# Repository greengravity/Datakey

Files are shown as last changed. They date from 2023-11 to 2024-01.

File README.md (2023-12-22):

### Datastorage
## What is it?
In short, it is a physical offline-device to store secret information like account data or banking informations.  
While mobile apps can do things like this, its always possible to have some spyware installed with the last gaming app or whatever.  
Because of that i dont trust mobiles too much and so i decided to make this little project.  

# How it Works?
It is pretty simple, the device have 6 Buttons for input and a 1.7" Display for output.  
Just enter your pincode and you will be able to browse through your entries.  

Every entry have a name and up to 5 additional tokens to store informations like username/password or other things.  
You can add/delete or modify entries directly on the device, without the need of a mobile-device or computer.  

The tokens itself are entered with a virtual keyboard on the device.  
Its like entering the name with a gamecontroller on a gamingconsole.  

Everything entered will be encrypted with a masterkey and stored on a micro-sd card.  
The masterkey is a secret that only the user know, if it get lost, you may not be able to restore your data anymore.  

Usually the masterkey is stored in the device, so you dont need to rember it all the time.  
But if you or someone else mess up the pincode verification, the masterkey get deleted from the device (for security reasons).  
Thats why it is important to have the masterkey stored or memorized safely.  

The Device can also act as an keyboard.  
After you connected the device to your pc via usb, you can select an entry/token and push it to the pc.  
like entering the data with a keyboard.  
This type of communication is pretty much one-way, so the connected system cannot control the output of the device.  
It should be safe to use it like that.  

# Features
- 128-Bit AES-CBC encryption over all entries
* Offline input/output
* USB-Keyboard function to push data to connected systems
* USB-Charging
* Long standby because of low power consumption ( about 2 years - 8.5müAmp usage with 150mAh Battery )
* Usage of Fat32 filesystem, so you can backup your data on your PC, this is safe because the data is completely encrypted, but make sure the masterkey stay separated from the data (dont store the masterkey on the pc too)
+ TETRIS :)

# What do you need to start?
- The Device
* An micro sd-card, formated with a Fat32 filesystem.
+ A micro-usb cable to charge the device

Enter the sd-card to the slot on the side of the device and open it.  
You will be questioned about the masterkey.  
Enter one, the longer the better.  
Then you will be questioned about your pincode.  
This looks like a game, but it is actually just a disguise as an additional security layer.  
Enter one and Reenter it, you can use all 6 buttons for it.  
You should end up on an empty screen showing the entrylist.  
Gratulations, you can now add/modify entries in your list, using the context menus.  

# Build the Device
To build the device you need a bunch of things

The electrical components (see components.csv in the Docs)  
The Printboard (see datakeyboard/ for the kicad project or datakeyboard/gerber for the gerberfiles to send to your pcb-maker)  
The MPLAB X IDE from microchip as well as an programmer device like the PICKit to build and programm the pic24fj128gb204 microcontroller  
A 3D Printer to print the housing.  
A tiny piece of thin copper or iron and something to cut it, it become the inlay for the housing to trigger the pogopins when open or close the cap.  
A possibility to solder SMD-Parts

Checkout c0pperdragon and his amazing HotPlate project on github for this (also available on tindie)

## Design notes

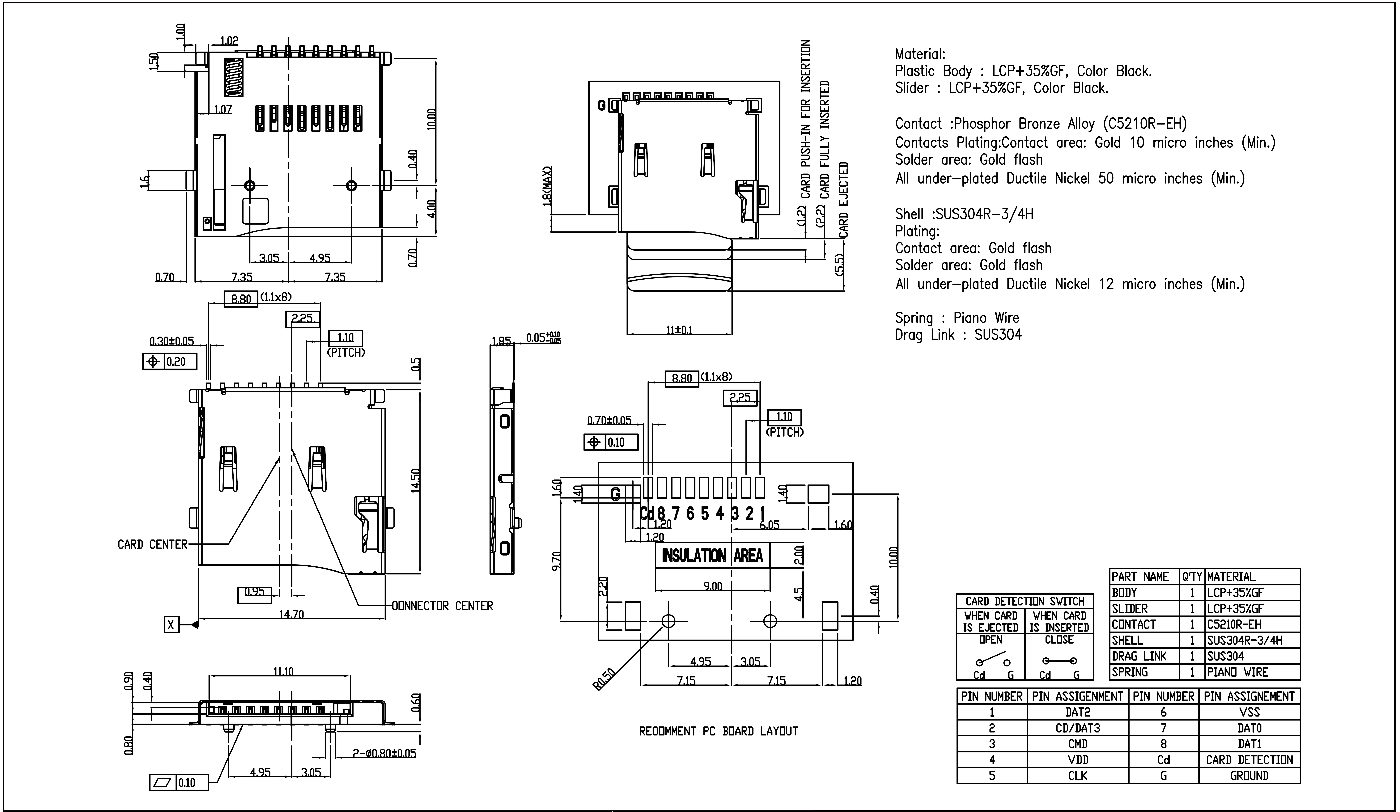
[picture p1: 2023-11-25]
docs/MICRO-SDCARD-1.jpg

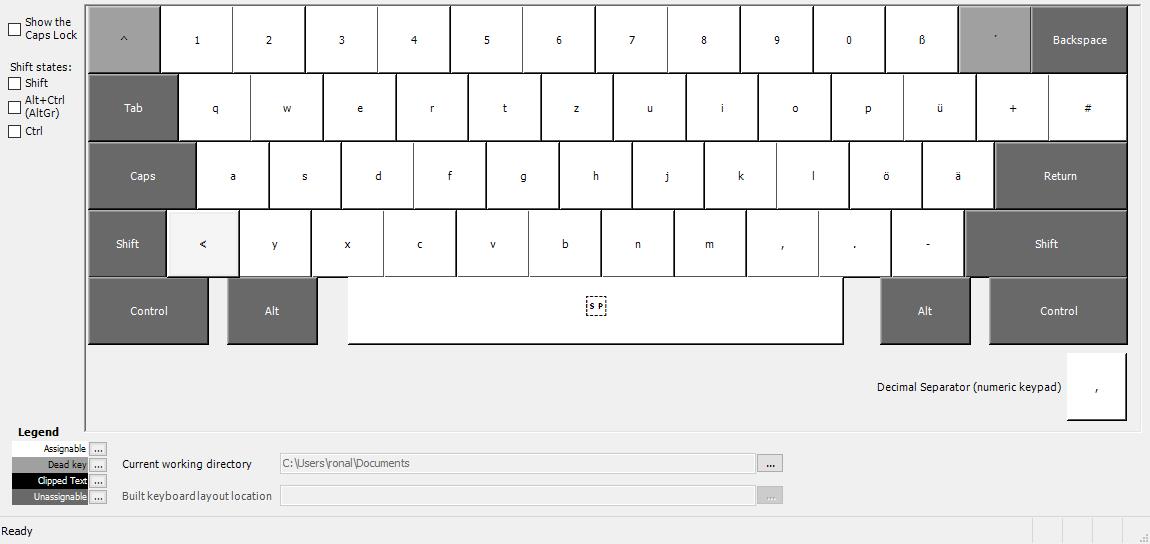
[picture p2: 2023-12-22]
assettools/locals/fonts/de-DE/Layout01.jpg

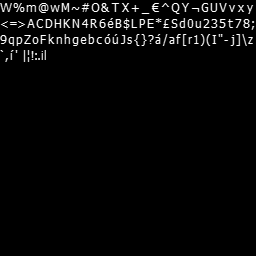
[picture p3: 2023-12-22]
assettools/locals/fonts/en-GB/font_0.png

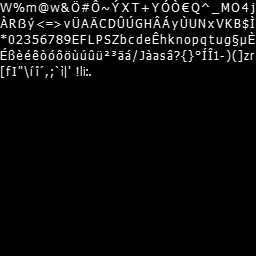
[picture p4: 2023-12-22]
assettools/locals/fonts/de-DE/font_0.png

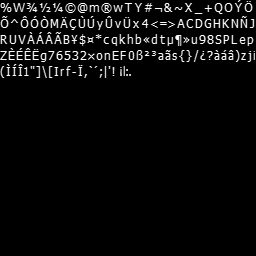
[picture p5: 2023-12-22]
assettools/locals/fonts/en-US/font_0.png

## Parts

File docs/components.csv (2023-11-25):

Item | Qty | Reference(s) | Value | LibPart | Footprint | Datasheet
1 | 3 | C1, C2, C3 | 10uF | Device:C_Small | Capacitor_SMD:C_0805_2012Metric_Pad1.18x1.45mm_HandSolder | ~
2 | 7 | C5, C6, C7, C8, C9, C10, C11 | 100nF | Device:C_Small | Capacitor_SMD:C_0603_1608Metric_Pad1.08x0.95mm_HandSolder | ~
3 | 2 | D1, D2 | LED | Device:LED | Diode_SMD:D_1206_3216Metric_Pad1.42x1.75mm_HandSolder | ~
4 | 1 | D3 | BAS40-06 | Library:BAS40-06 | Package_TO_SOT_SMD:SOT-23 | ~
6 | 1 | JCARD1 | Micro_SD_Card_Det | Connector:Micro_SD_Card_Det | Library:microSD_Unknown | Micro SD-Card slot, have a look at the image in the doc folder for the correct dimensions that match the footprint
7 | 1 | JDISP1 | Conn_01x08 | Connector_Generic:Conn_01x08 | Connector_PinHeader_2.54mm:PinHeader_1x08_P2.54mm_Vertical | Display from A-Z Delivery – have a look at the datasheet in the doc folder
9 | 1 | JUSB1 | USB_OTG | Connector:USB_OTG | Library:USB_Micro-B_Unknown | ~
10 | 5 | Q1, Q2, Q3, Q4, Q5 | NX2301P | Transistor_FET:BSS83P | Package_TO_SOT_SMD:SOT-23 | ~
11 | 1 | R1 | 100 | Device:R_Small | Resistor_SMD:R_0805_2012Metric_Pad1.20x1.40mm_HandSolder | ~
12 | 3 | R2, R3, R4 | 1k | Device:R_Small | Resistor_SMD:R_0805_2012Metric_Pad1.20x1.40mm_HandSolder | ~
13 | 1 | R5 | 2.2k | Device:R_Small | Resistor_SMD:R_0805_2012Metric_Pad1.20x1.40mm_HandSolder | ~
14 | 7 | R6, R7, R9, R10, R11, R12, R13 | 10k | Device:R_Small | Resistor_SMD:R_0805_2012Metric_Pad1.20x1.40mm_HandSolder | ~
15 | 1 | R8 | 100k | Device:R_Small | Resistor_SMD:R_0805_2012Metric_Pad1.20x1.40mm_HandSolder | ~
16 | 6 | SW1, SW2, SW3, SW4, SW5, SW6 | SW_Push | Switch:SW_Push | Button_Switch_SMD:SW_Push_1P1T_NO_6x6mm_H9.5mm | ~
17 | 1 | U1 | PIC24FJ128GB204 | Library:PIC24FJ128GB204 | Package_QFP:TQFP-44_10x10mm_P0.8mm
18 | 1 | U2 | MCP73831-2-OT | Battery_Management:MCP73831-2-OT | Package_TO_SOT_SMD:SOT-23-5 | ~
19 | 1 | U3 | STLQ015M30R | Regulator_Linear:AP131-30 | Package_TO_SOT_SMD:SOT-23-5 | ~
20 | 2 |  | 33mm extended | Pogopins |  | ~ soldered with fine cables to JCASE1 and JCASE2
21 | 1 |  | 3,7V, 150mAh | Lipo-Battery |  | https://www.amazon.de/dp/B08215WQMQ?ref=ppx_yo2ov_dt_b_product_details&th=1

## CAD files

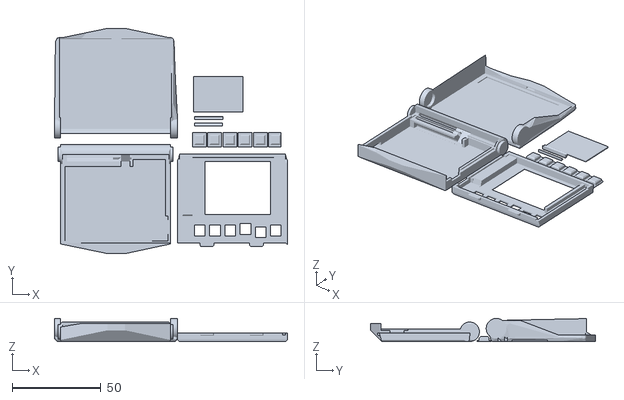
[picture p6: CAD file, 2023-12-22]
housing/housing_complete.stl
131.4 x 127.0 x 13.1

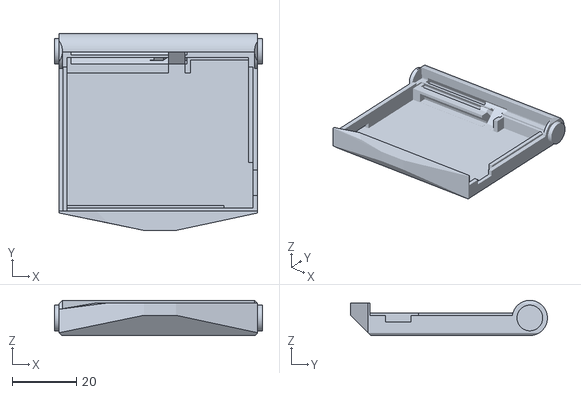
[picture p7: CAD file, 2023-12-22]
housing/gehauese.stl
65.0 x 61.5 x 11.0

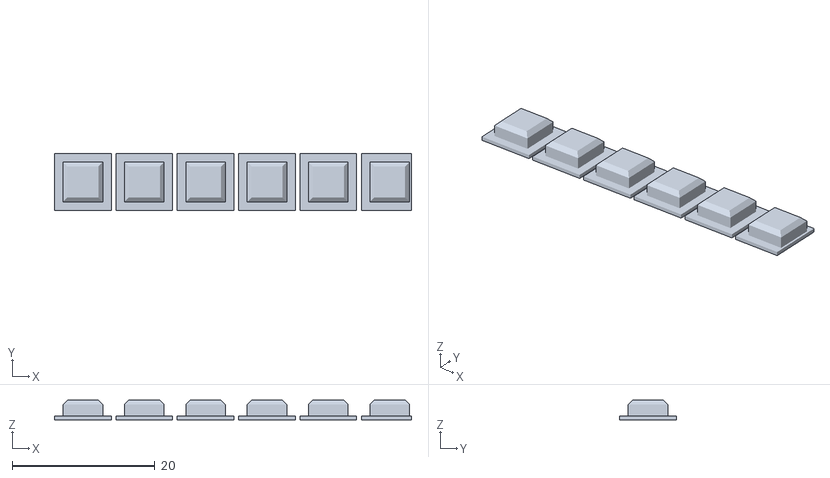
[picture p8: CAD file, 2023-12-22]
housing/buttons.stl
50.0 x 7.97 x 2.76

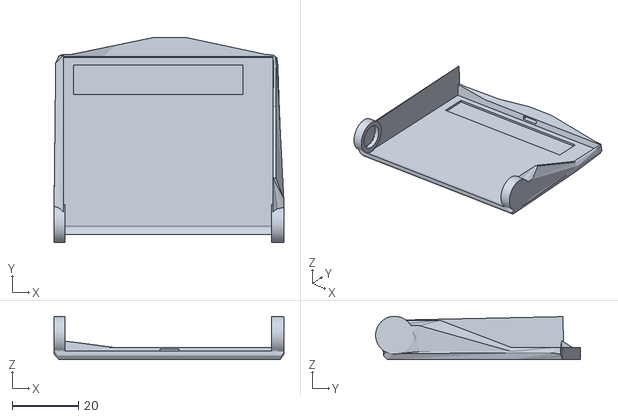
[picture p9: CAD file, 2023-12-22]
housing/deckel.stl
69.3 x 61.7 x 13.1

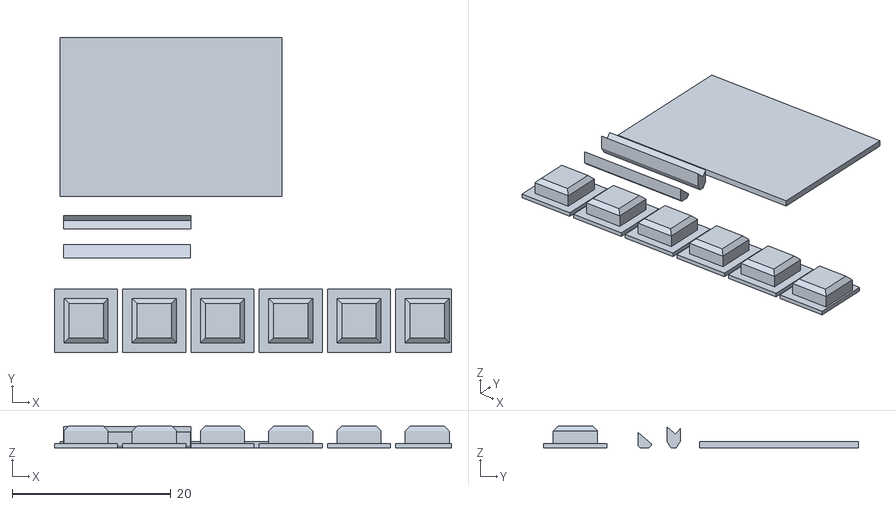
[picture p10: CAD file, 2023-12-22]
housing/extras.stl
50.0 x 39.6 x 2.76

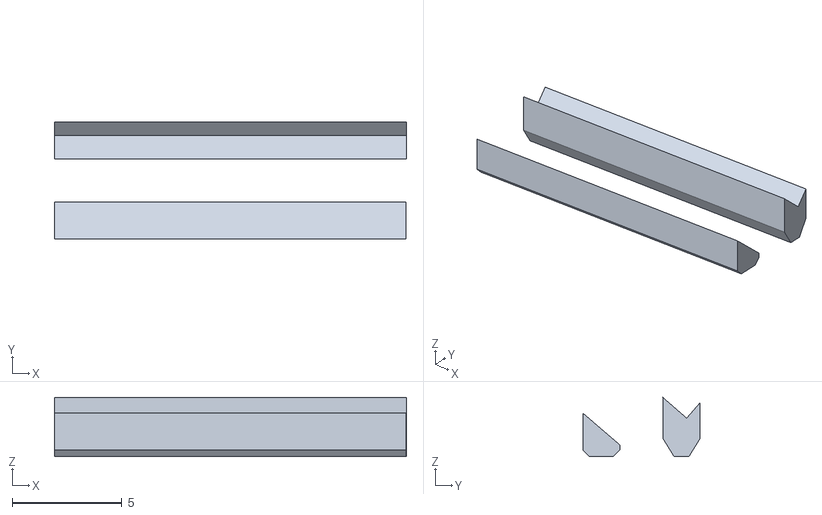
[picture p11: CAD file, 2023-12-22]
housing/pogoblock.stl
16.0 x 5.33 x 2.69

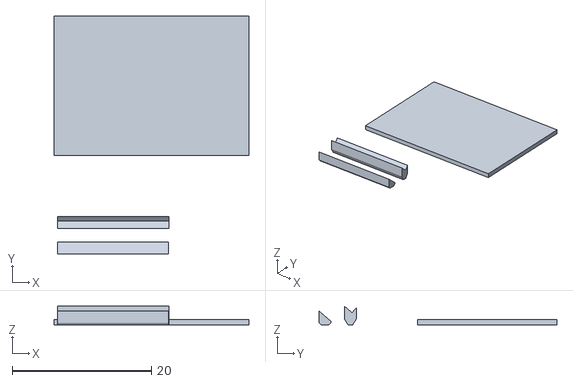
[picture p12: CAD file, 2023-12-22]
housing/einlagen.stl
28.0 x 34.1 x 2.69

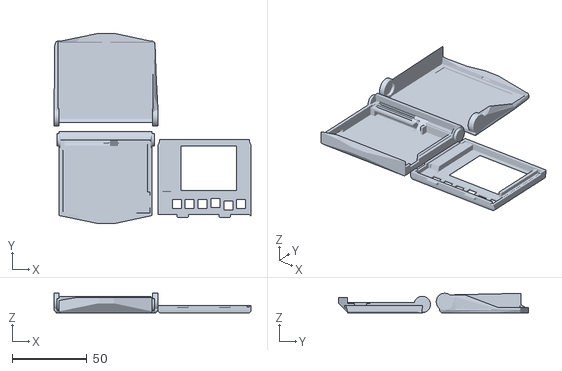
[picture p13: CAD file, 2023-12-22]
housing/housing.stl
131.4 x 127.0 x 13.1

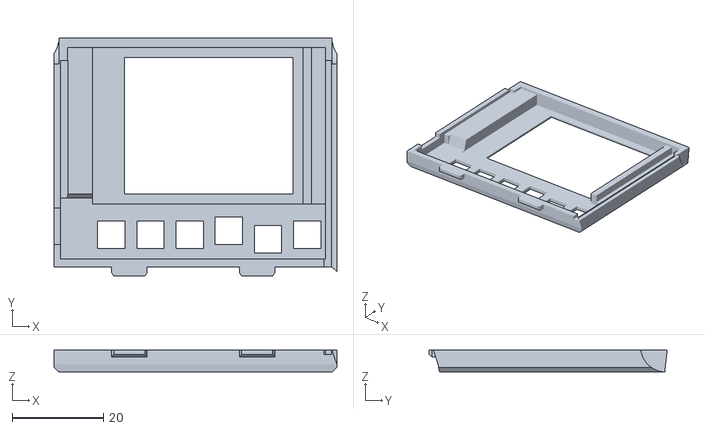
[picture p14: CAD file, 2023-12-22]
housing/gehauese_inlay.stl
62.0 x 52.2 x 4.77

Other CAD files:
housing/housing_complete.blend

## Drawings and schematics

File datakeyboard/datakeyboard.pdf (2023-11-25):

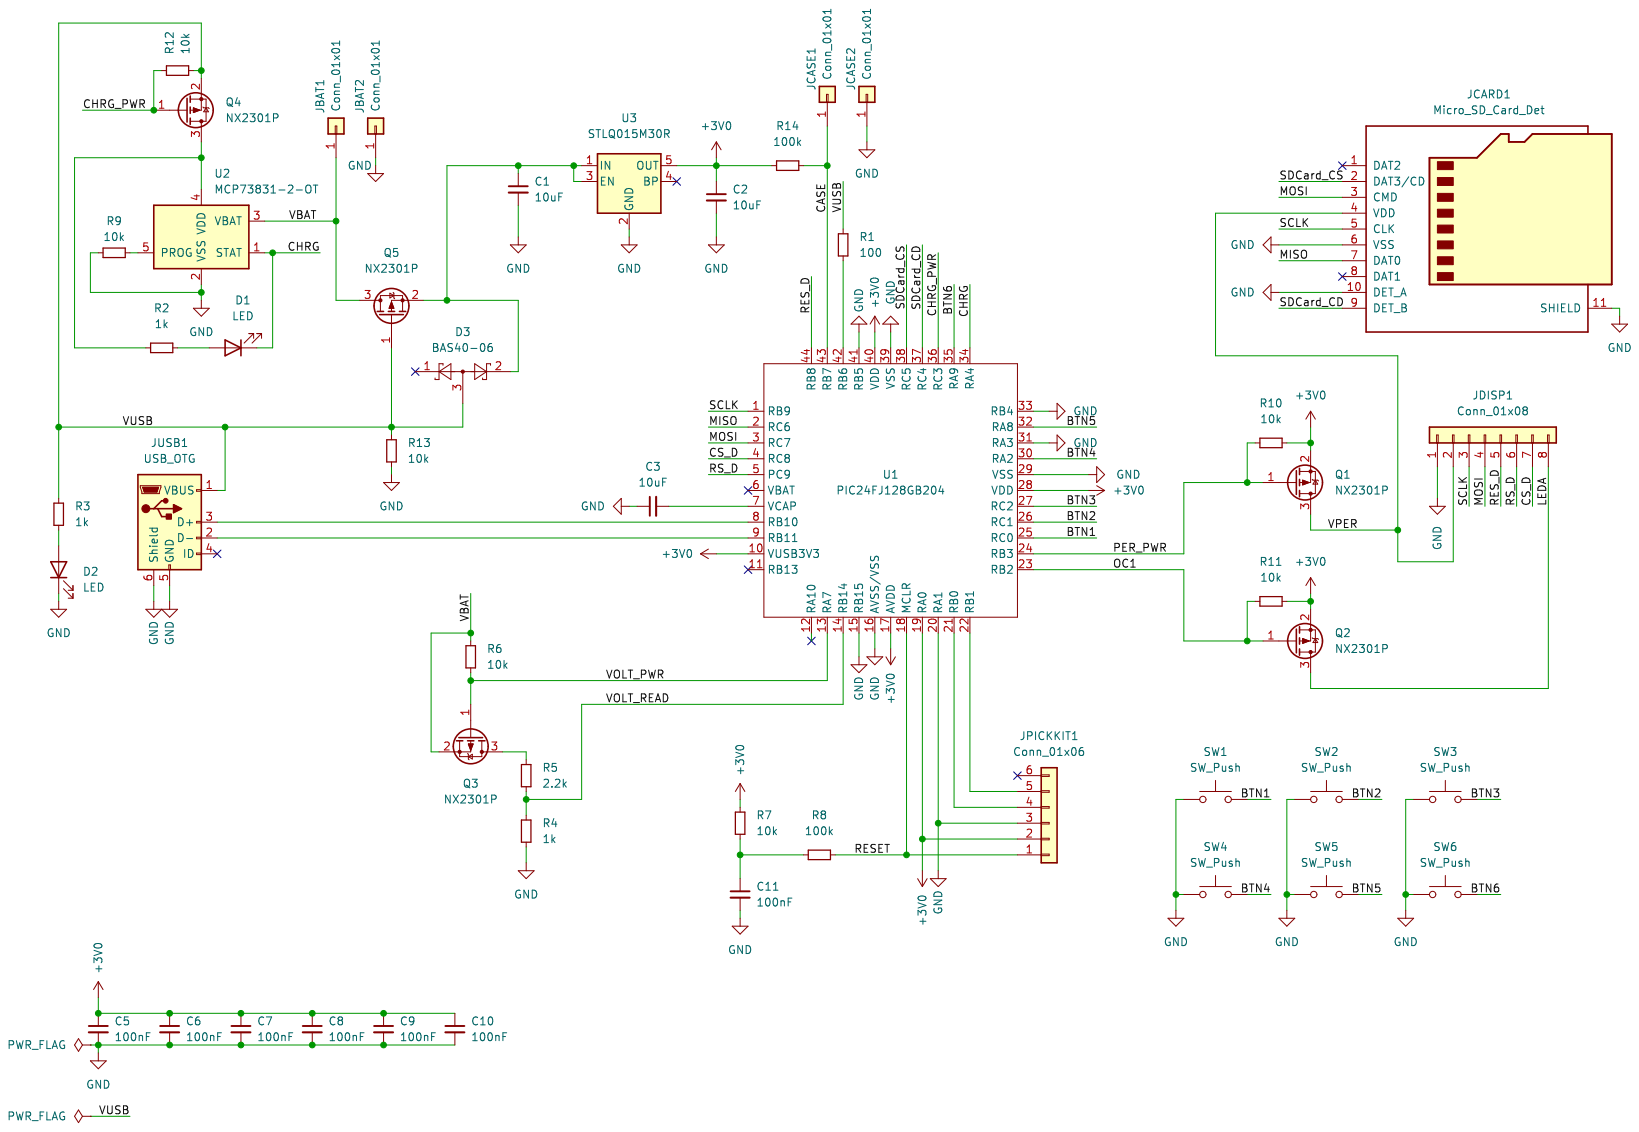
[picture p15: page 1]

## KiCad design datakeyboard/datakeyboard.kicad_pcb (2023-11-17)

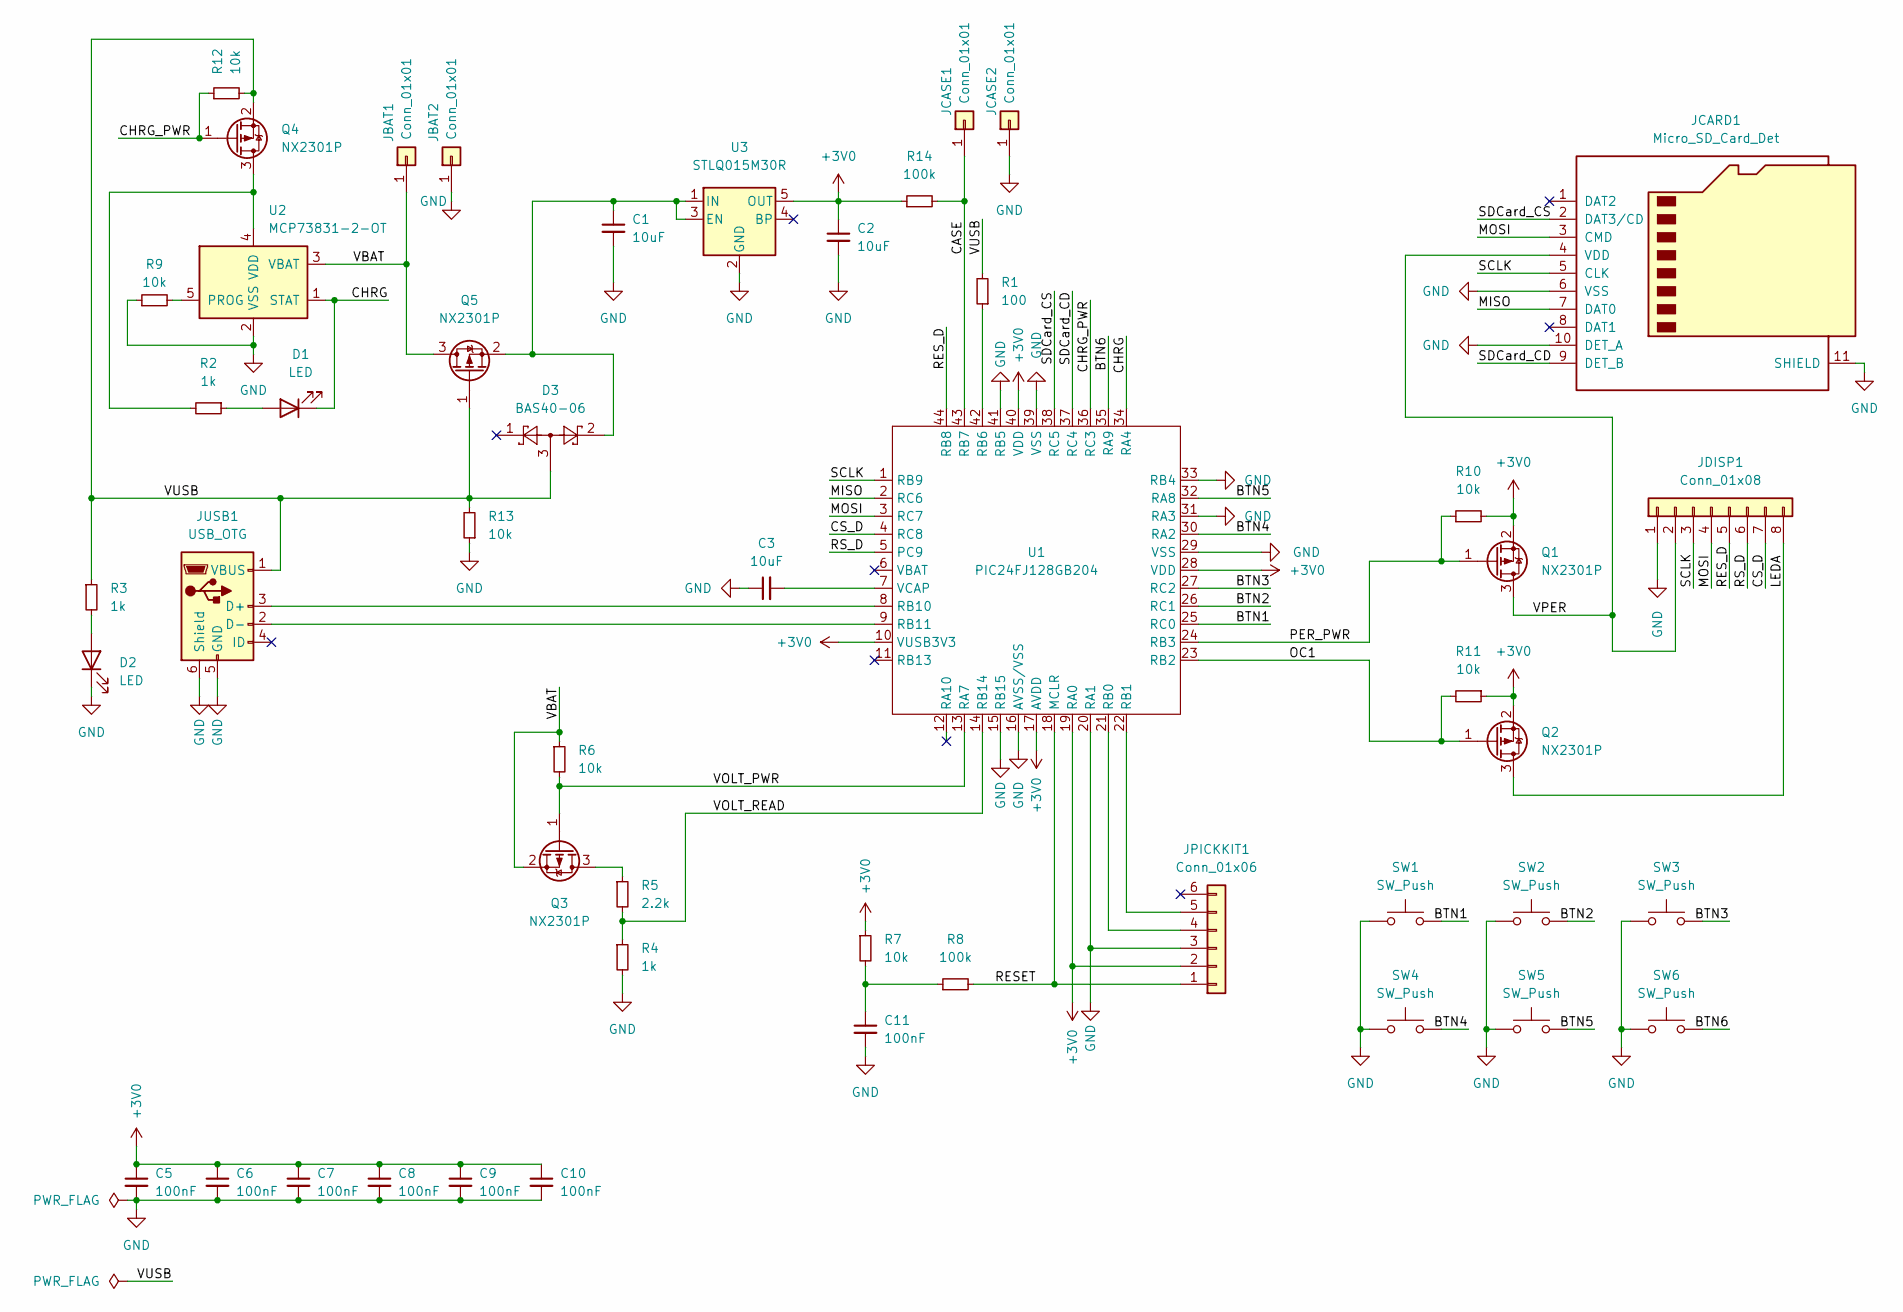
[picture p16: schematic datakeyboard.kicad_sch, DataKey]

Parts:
C1, C2, C3: 10uF; C_0805_2012Metric_Pad1.18x1.45mm_HandSolder
C5, C6, C7, C8, C9, C10, C11: 100nF; C_0603_1608Metric_Pad1.08x0.95mm_HandSolder
D1, D2: LED; D_1206_3216Metric_Pad1.42x1.75mm_HandSolder
D3: BAS40-06; SOT-23
JBAT1, JBAT2: Conn_01x01; TestPoint_Pad_2.0x2.0mm
JCARD1: Micro_SD_Card_Det; microSD_Unknown
JCASE1, JCASE2: Conn_01x01; TestPoint_Pad_2.0x2.0mm
JDISP1: Conn_01x08; PinHeader_1x08_P2.54mm_Vertical
JPICKKIT1: Conn_01x06; PinHeader_1x06_P2.54mm_Vertical
JUSB1: USB_OTG; USB_Micro-B_Unknown
Q1, Q2, Q3, Q4, Q5: NX2301P; SOT-23
R1: 100; R_0805_2012Metric_Pad1.20x1.40mm_HandSolder
R2, R3, R4: 1k; R_0805_2012Metric_Pad1.20x1.40mm_HandSolder
R5: 2.2k; R_0805_2012Metric_Pad1.20x1.40mm_HandSolder
R6, R7, R9, R10, R11, R12, R13: 10k; R_0805_2012Metric_Pad1.20x1.40mm_HandSolder
R8, R14: 100k; R_0805_2012Metric_Pad1.20x1.40mm_HandSolder
SW1, SW2, SW3, SW4, SW5, SW6: SW_Push; SW_Push_1P1T_NO_6x6mm_H9.5mm
U1: PIC24FJ128GB204; TQFP-44_10x10mm_P0.8mm
U2: MCP73831-2-OT; SOT-23-5
U3: STLQ015M30R; SOT-23-5

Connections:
+3V0: C2.1, C5.1, C6.1, C7.1, C8.1, C9.1, C10.1, JPICKKIT1.2, Q1.2 (S), Q2.2 (S), R7.1, R10.2, R11.1, R14.1, U1.10 (VUSB3V3), U1.17 (AVDD), U1.19 (RA0), U1.28 (VDD), U1.40 (VDD), U3.5 (OUT)
/BTN1: SW1.2, U1.25 (RC0)
/BTN2: SW2.2, U1.26 (RC1)
/BTN3: SW3.2, U1.27 (RC2)
/BTN4: SW4.2, U1.30 (RA2)
/BTN5: SW5.2, U1.32 (RA8)
/BTN6: SW6.2, U1.35 (RA9)
/CASE: JCASE1.1, R14.2, U1.43 (RB7)
/CHRG: D1.1 (K), U1.34 (RA4), U2.1 (STAT)
/CHRG_PWR: Q4.1 (G), R12.1, U1.36 (RC3)
/CS_D: JDISP1.7, U1.4 (RC8)
/LEDA: JDISP1.8, Q2.3 (D)
/MISO: JCARD1.7 (DAT0), U1.2 (RC6)
/MOSI: JCARD1.3 (CMD), JDISP1.4, U1.3 (RC7)
/OC1: Q2.1 (G), R11.2, U1.23 (RB2)
/PER_PWR: Q1.1 (G), R10.1, U1.24 (RB3)
/RESET: JPICKKIT1.1, R8.2, U1.18 (MCLR)
/RES_D: JDISP1.5, U1.44 (RB8)
/RS_D: JDISP1.6, U1.5 (PC9)
/SCLK: JCARD1.5 (CLK), JDISP1.3, U1.1 (RB9)
/SDCard_CD: JCARD1.9 (DET_B), U1.37 (RC4)
/SDCard_CS: JCARD1.2 (DAT3/CD), U1.38 (RC5)
/VBAT: JBAT1.1, Q3.2 (S), Q5.3 (D), R6.1, U2.3 (VBAT)
/VOLT_PWR: Q3.1 (G), R6.2, U1.13 (RA7)
/VOLT_READ: R4.1, R5.2, U1.14 (RB14)
/VPER: JCARD1.4 (VDD), JDISP1.2, Q1.3 (D)
/VUSB: D3.3, JUSB1.1 (VBUS), Q4.2 (S), Q5.1 (G), R1.2, R3.1, R12.2, R13.2
GND: C1.2, C2.2, C3.1, C5.2, C6.2, C7.2, C8.2, C9.2, C10.2, C11.2, D2.1 (K), JBAT2.1, JCARD1.6 (VSS), JCARD1.10 (DET_A), JCARD1.11 (SHIELD), JCASE2.1, JDISP1.1, JPICKKIT1.3, JUSB1.5 (GND), JUSB1.6 (Shield), R4.2, R9.1, R13.1, SW1.1, SW2.1, SW3.1, SW4.1, SW5.1, SW6.1, U1.15 (RB15), U1.16 (AVSS/VSS), U1.20 (RA1), U1.29 (VSS), U1.31 (RA3), U1.33 (RB4), U1.39 (VSS), U1.41 (RB5), U2.2 (VSS), U3.2 (GND)
unnamed: C1.1, D3.2, Q5.2 (S), U3.1 (IN), U3.3 (EN)
unnamed: C3.2, U1.7 (VCAP)
unnamed: C11.1, R7.2, R8.1
unnamed: D1.2 (A), R2.1
unnamed: D2.2 (A), R3.2
unnamed: JPICKKIT1.4, U1.21 (RB0)
unnamed: JPICKKIT1.5, U1.22 (RB1)
unnamed: JUSB1.2 (D-), U1.9 (RB11)
unnamed: JUSB1.3 (D+), U1.8 (RB10)
unnamed: Q3.3 (D), R5.1
unnamed: Q4.3 (D), R2.2, U2.4 (VDD)
unnamed: R1.1, U1.42 (RB6)
unnamed: R9.2, U2.5 (PROG)

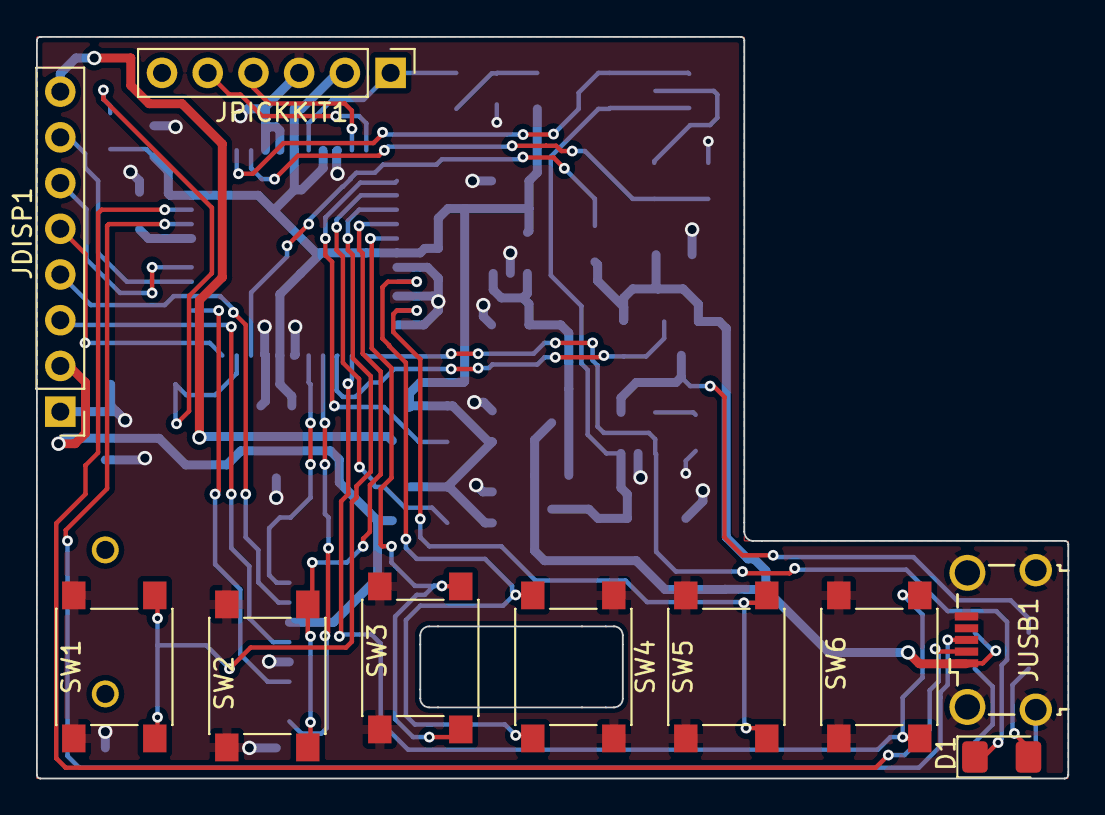
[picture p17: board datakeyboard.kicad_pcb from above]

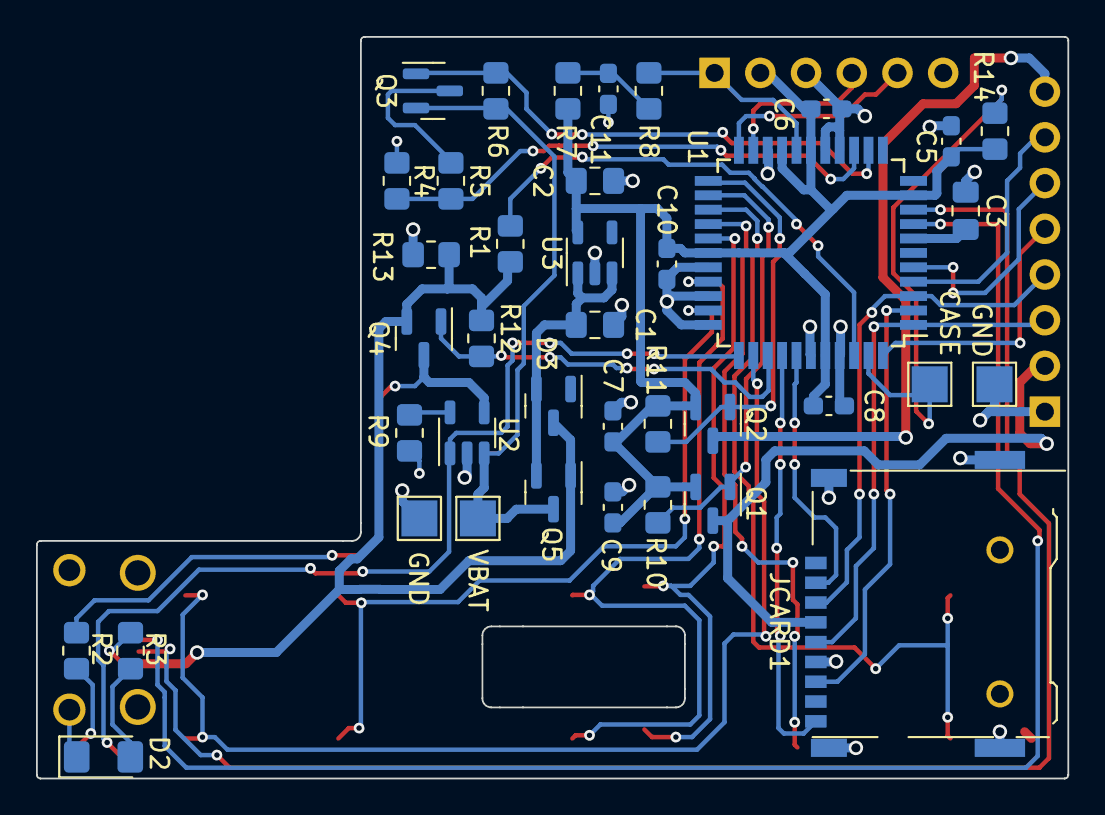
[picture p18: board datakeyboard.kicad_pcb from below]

Board: 2 copper layers, 57.3 x 41.2 mm, 49 parts (39 on the bottom side), 41 nets.

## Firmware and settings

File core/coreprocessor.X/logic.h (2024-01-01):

/* 
 * File:   
 * Author: greengravity
 * Comments:
 * Revision history: 
 */


#ifndef XC_LOGIC_H
#define	XC_LOGIC_H

#include <xc.h> // include processor files - each processor file is guarded.  
#include <stdbool.h>
#include "fs/ff.h"
#include "assets.h"
#include "mcc_generated_files/rtcc.h"

#define CTX_BUFFER_SIZE 2000
#define MIN_PIN_SIZE 3
#define MAX_PIN_SIZE 20
#define DEFAULT_PIN_SIZE 8
#define DEFAULT_PIN_TRIES 6
#define MAX_PIN_TRIES 9
#define MIN_PIN_TRIES 1

#define TEXT_WORK_TRESHHOLD 17
#define MAX_TEXT_LEN 1023
#define TEXTAREA_WIDTH 150
#define TEXTAREA_VIEWPORT_LINES 3
#define TEXTVIEWER_LINES 6
#define OVERVIEW_LINES 5
#define MAX_TEXTAREA_SPACE_BREAK 80
//#define TEXTAREA_RINGBUFFER_LEN 64
#define TOKEN_BLOCK_SIZE 4096  //256*16 
#define TOKEN_READ_MOD_BUFFERSIZE 512 //TOKEN_BLOCK_SIZE % TOKEN_READ_MOD_BUFFERSIZE must be zero
#define MAX_OVERVIEW_ENTRY_COUNT 16
#define MAX_SEARCH_LEN 20
//#define OVERVIEW_RELOAD_OFFS (MAX_OVERVIEW_ENTRY_COUNT / 2 - (OVERVIEW_LINES + 1))

typedef enum {   
    PFLD_NOTHING,
    PFLD_GROUND,
    PFLD_OWL,
    PFLD_LITTLEDRAGON,
    PFLD_TREE,
    PFLD_STONE,
    PFLD_SHIELD,
    PFLD_DRAGON,               
    PFLD_CRACKSTONE,                           
    PFLD_SWORD,                           
    PFLD_GRAIL,                           
} PINFIELD;


typedef enum {
    NEW,
    NAME,
    USER,        
    KEY1,
    KEY2,
    URL,                
    INFO,
    CHECK,
} TOKEN_TYPE;

typedef enum {
    MASTERKEY_GEN,
    MASTERKEY_VERIFY,
    MASTERKEY_CHECK,
    SEARCHFIELD,
    TOKEN,                            
}INPUT_TYPE;

typedef enum {
    USB_MODE_OFF,
    USB_MODE_KEYBOARD          
} USB_MODE;

typedef struct {
    uint16_t highlight_color1;
    uint16_t highlight_color2;
    uint8_t brightness;
    USB_MODE umode;    
    uint8_t pin_tries;
    uint8_t pin_len;    
} DEVICE_OPTIONS;

typedef struct {
    TOKEN_TYPE type;
    uint8_t textid; 
    uint8_t textidview; 
    uint8_t tkname;
} TOKEN_CONFIG;

typedef enum {    
    UNCHANGED,
    REFRESH,    
    ONBUTTON_PRESS,
    ONBUTTON_RELEASE,
    ONBUTTON_DOWN,
    REMOVECHAR,
    ANIMATION,
    ANIMATION2,
    LOADENTRY,
    AREASWITCH,
    IO_UPDATE,
} RENDER_INFO;

typedef enum {
    EMPTY,
    ERROR,
    ERROR_CONTEXT,
    ERROR_SD_CD,
    ERROR_SD_FAILURE,
    INITIAL,
    PIN_INPUT,
    VERIFY_KEY_AFTER_PIN,
    KEY_INPUT, 
    ENTRY_OVERVIEW,
    ENTRY_DETAIL,
    GAME_TETRIS,
    USB_PUSH,
    VIEW_TOKEN,
    EDIT_ENTRY,
    SEARCH_ENTRIES,
    MESSAGEBOX,
    CHOOSEBOX,
    DEVICEOPTIONS,            
    PINOPTIONS,
    //OPTIONS2
} CONTEXT_TYPE;

typedef enum {
    CHBX_ABORT,
    CHBX_SEARCH_ENTRY,
    CHBX_CREATE_ENTRY,
    CHBX_DELETE_ENTRY,
    CHBX_OPTIONS,
    CHBX_DEVICEOPTIONS,
    CHBX_PINOPTIONS,
    CHBX_GAMES,
    CHBX_RETURN_OVERVIEW,
    CHBX_EDIT_TOKEN,
    CHBX_DELETE_TOKEN,
    CHBX_PUSH_TOKEN        
} CHBX_SELECTIONS;

typedef enum {
    MSGB_NO_RESULT,
    MSGB_EDIT_ABORT_YES,
    MSGB_EDIT_ABORT_NO,
    MSGB_EDIT_ACCEPT_YES,
    MSGB_EDIT_ACCEPT_NO,  
    MSGB_DELETE_ENTRY_YES,
    MSGB_DELETE_ENTRY_NO,
    MSGB_DELETE_TOKEN_YES,
    MSGB_DELETE_TOKEN_NO,
    MSGB_MKEY_ERROR_OK,
    MSGB_SEARCHINFO_COMMIT,
} MSGB_CHOICES;

typedef enum {
    DEVCST_BATTERY,
    DEVCST_CHARGER,
    DEVCST_USB,
} DEVICE_CONNECTION_STATE;

typedef enum {    
    TETS_I,
    TETS_O,
    TETS_T,
    TETS_L,
    TETS_J,
    TETS_Z,
    TETS_S,     
    TETS_EMPTY,
} TETRIS_STONES;

extern const uint8_t tetris_piecesize[];
extern const uint8_t tetris_pieces[];


typedef struct {
    char msg[256];
} CTX_ERROR;

typedef struct {    
    RENDER_INFO rinf;
    INPUT_TYPE inp;
    TOKEN_TYPE type;    
    MSGB_CHOICES mboxresult;
    uint8_t datachanged;
    uint8_t okbmap;   //old keymap
    uint8_t kbmap;    //curr keymap
    uint8_t okbx;     //old keyx - for animation
    uint8_t okby;     //old keyy - for animation  
    uint8_t kbx;      //keyx
    uint8_t kby;      //keyy
    uint8_t oselarea; //old working area 
    uint8_t selarea;  //current working area
    uint8_t tewpx;    //textarea current writer x position
    uint8_t text[MAX_TEXT_LEN + TEXT_WORK_TRESHHOLD];
    uint8_t __pad1;
    uint16_t tavccoff;  //textarea viewport current character offset
    uint16_t tavcloff;  //textarea viewport current lineoffset
    uint16_t tewp;    //textarea current writer position
    uint16_t tlen;    //current length of text        
} IO_CONTEXT;


//Context for Pin Input
typedef struct {
    TETRIS_STONES field[200];
    int currx;
    int curry;      
    int currlvllines;
    TETRIS_STONES curr;
    TETRIS_STONES next;   
    uint8_t currrot;
    bool gameover;
    bool startpause;
    bool b2btetris;
    uint32_t lvl;
    uint32_t score;   
    uint32_t lines;
} CTX_TETRIS;


//Context for Pin Input
typedef struct {
    bool generatenew;
    bool pinIsInitial;
    bool verify;
    bool error;
    bool haderror;
    bool errorchecked;
    uint8_t ppos;    
    uint8_t pin[MAX_PIN_SIZE];
    uint8_t verifypin[MAX_PIN_SIZE];
    uint8_t pinerr;
    uint8_t px;
    uint8_t py;
    uint8_t field[64];    
    uint8_t extrasteps;    
} CTX_PIN_INPUT;

typedef struct { 
    IO_CONTEXT io;
    bool fschecked;
    bool generatemode;
    uint8_t generatedkey[16];
    bool error;
    bool haderror;    
} CTX_KEY_INPUT;

typedef struct {
    bool loaded;
    TCHAR path[16];
    uint8_t name[48];
    uint8_t __pad1;
} CTX_OVERVIEW_ENTRY;


typedef struct {        
    bool initialized;
    bool needinitsearch;    
    uint8_t ohighlightpos;  
    uint8_t searchstr[MAX_SEARCH_LEN];            
    uint8_t searchsuccessful;
    CTX_OVERVIEW_ENTRY entries[MAX_OVERVIEW_ENTRY_COUNT];
    uint16_t cursor;
    uint16_t bufferstart;
    uint16_t bufferlen;
    //uint16_t entrycenter;
    uint16_t entrycount;
} CTX_ENTRY_OVERVIEW;

typedef struct {
    TOKEN_TYPE type;
    uint8_t isset;
    uint8_t text[48];   
    uint8_t __pad1;
} CTX_ENTRY_DETAIL_TOKEN;

typedef struct {
    uint16_t tlen;
    uint8_t text[MAX_TEXT_LEN + TEXT_WORK_TRESHHOLD];     
} CTX_USB_PUSH;

typedef struct {    
    TCHAR path[16];
    TOKEN_TYPE selected;
    TOKEN_TYPE oselected;
    CTX_ENTRY_DETAIL_TOKEN tokeninfo[6];
    uint8_t tokencount;
    uint8_t __pad1;
    uint16_t overviewcursor;
} CTX_ENTRY_DETAIL;


typedef struct {    
    IO_CONTEXT io;
    TCHAR path[16];
    uint16_t overviewcursor;
} CTX_EDIT_ENTRY;


typedef struct {      
    IO_CONTEXT io;    
    uint8_t searchstr[MAX_SEARCH_LEN];      
    uint16_t overviewcursor;
} CTX_SEARCH_ENTRIES;
             
typedef struct {    
    uint8_t text[MAX_TEXT_LEN + TEXT_WORK_TRESHHOLD];
    TOKEN_TYPE type;
    uint8_t __pad1;
    uint16_t tlen;
    uint16_t currline;
    uint16_t lines;
} CTX_VIEW_TOKEN;

typedef struct {
    uint8_t msgtxt[50];
    uint8_t sel;
    uint8_t osel;
    uint8_t  choicecount;
    uint8_t __pad1;
    MSGB_CHOICES mchoices[6];    
    uint16_t mchoiceicon[6];    
} CTX_MSG_BOX;

typedef struct {
    uint16_t textid[6];
    uint8_t selectid[6];
    uint8_t options;
    CHBX_SELECTIONS selected;
    CHBX_SELECTIONS oselected;    
} CTX_CHOOSE_BOX;


typedef struct {
    bcdTime_t time;
    uint8_t selected;
    uint8_t oselected;    
    uint8_t holdtime;
    uint8_t __pad1;
} CTX_DEVICEOPTIONS;

typedef struct {
    uint8_t selected;
    uint8_t oselected;
    uint8_t pin_len;
    uint8_t __pad1;
} CTX_PINOPTIONS;


//Context storage
typedef struct {
    uint16_t ctxptr; 
    uint16_t bufferlen;
    uint8_t *ctxbuffer;
    uint8_t ctxtype;    
    uint8_t power;       
    bool fsmounted;
    bool fileopen;    
    uint8_t chrg_open;
    uint8_t adc_rw_state;
    uint8_t __pad1;
    RENDER_INFO rinf;
    DEVICE_CONNECTION_STATE dcstate;
    uint8_t bus_sense;        
    uint16_t analogtest;
    FATFS drive;
} APP_CONTEXT;

extern const uint16_t highlight_color_tab[];
extern const TOKEN_CONFIG token_configs[];
extern DEVICE_OPTIONS device_options;

bool isPinSet();
bool isKeySet( );
void setMasterKey(uint8_t *key);
uint8_t* getMasterKey();
void swipeKeys();
uint8_t verifyMasterKey( );
bool isKeyEncr();
void setKeyEncr(bool encr);


void tet_getRotatedShape( uint8_t *shape, TETRIS_STONES piece, uint8_t rot );
uint8_t getCharactersInLine(uint8_t* text, uint16_t coff, uint16_t maxchars );
bool setContext(APP_CONTEXT *ctx, CONTEXT_TYPE type);
void setInitialContext( APP_CONTEXT* ctx );
void updateContext(APP_CONTEXT* ctx);

#endif	/* XC_HEADER_TEMPLATE_H */

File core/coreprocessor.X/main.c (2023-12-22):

/*
 * File:   main.c
 * Author: greengravity
 *
 * Created on 14. Januar 2023, 16:01
 */
#include "main.h"
#include "logic.h"
#include "ui.h"
#include "mcc_ext.h"
#include "mcc_generated_files/system.h"

#include "mcc_generated_files/spi1_driver.h"
#include "display_driver.h"
#include "usb/usb.h"

//#include "mcc_generated_files/adc1.h"
#include "mcc_generated_files/oc1.h"
#include "mcc_generated_files/tmr2.h"

APP_CONTEXT ctx;
uint8_t contextbuffer[CTX_BUFFER_SIZE];

int main(void) {
    //most configuration happen 
    SYSTEM_Initialize();                      
    swipeKeys();
    
    ANSB |= 0x4000; //Set pin RB14 to analog
    AD1CON1bits.ADON = 0; // Turn off the ADC module       
    
    //configure the ADC module
    AD1CON1 = 0x8474; // Turn off the ADC module
    AD1CON2 = 0; // Select AVdd and AVss as reference voltages
    AD1CON3 = 0x1003;
    AD1CHS = 0x6; // Select RB14 as the input channel
    
    enableBUSCharge();
    USBDeviceInit();    
    
    ctx.ctxbuffer = contextbuffer;
    ctx.fsmounted = false;
    ctx.fileopen = false;        
    
    device_options.brightness = 100;
    device_options.highlight_color2 = device_options.highlight_color1 = highlight_color_tab[0];
    device_options.umode = USB_MODE_KEYBOARD;
    device_options.pin_len = DEFAULT_PIN_SIZE;
    device_options.pin_tries = DEFAULT_PIN_TRIES;
    
    setSleep(&ctx);  //Start in sleep mode

    //bootPeripherals(&ctx);    
    //setInitialContext(&ctx);
    
                      
    while (1) {
        updateContext(&ctx);
        renderUI(&ctx);
    }
 
    while (1);
    return 1;
}




#if defined(USB_INTERRUPT)

void __attribute__((interrupt, auto_psv)) _USB1Interrupt() {
    USBDeviceTasks();
}
#endif

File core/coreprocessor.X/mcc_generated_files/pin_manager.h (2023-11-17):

/**
  PIN MANAGER Generated Driver File

  @Company:
    Microchip Technology Inc.

  @File Name:
    pin_manager.h

  @Summary:
    This is the generated manager file for the PIC24 / dsPIC33 / PIC32MM MCUs device.  This manager
    configures the pins direction, initial state, analog setting.
    The peripheral pin select, PPS, configuration is also handled by this manager.

  @Description:
    This source file provides implementations for PIN MANAGER.
    Generation Information :
        Product Revision  :  PIC24 / dsPIC33 / PIC32MM MCUs - 1.171.1
        Device            :  PIC24FJ128GB204
    The generated drivers are tested against the following:
        Compiler          :  XC16 v1.70
        MPLAB 	          :  MPLAB X v5.50
*/

/*
    (c) 2020 Microchip Technology Inc. and its subsidiaries. You may use this
    software and any derivatives exclusively with Microchip products.

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
    IN NO EVENT WILL MICROCHIP BE LIABLE FOR ANY INDIRECT, SPECIAL, PUNITIVE,
    INCIDENTAL OR CONSEQUENTIAL LOSS, DAMAGE, COST OR EXPENSE OF ANY KIND
    WHATSOEVER RELATED TO THE SOFTWARE, HOWEVER CAUSED, EVEN IF MICROCHIP HAS
    BEEN ADVISED OF THE POSSIBILITY OR THE DAMAGES ARE FORESEEABLE. TO THE
    FULLEST EXTENT ALLOWED BY LAW, MICROCHIP'S TOTAL LIABILITY ON ALL CLAIMS IN
    ANY WAY RELATED TO THIS SOFTWARE WILL NOT EXCEED THE AMOUNT OF FEES, IF ANY,
    THAT YOU HAVE PAID DIRECTLY TO MICROCHIP FOR THIS SOFTWARE.

    MICROCHIP PROVIDES THIS SOFTWARE CONDITIONALLY UPON YOUR ACCEPTANCE OF THESE
    TERMS.
*/

#ifndef _PIN_MANAGER_H
#define _PIN_MANAGER_H
/**
    Section: Includes
*/
#include <xc.h>

/**
    Section: Device Pin Macros
*/
/**
  @Summary
    Sets the GPIO pin, RA10, high using LATA10.

  @Description
    Sets the GPIO pin, RA10, high using LATA10.

  @Preconditions
    The RA10 must be set to an output.

  @Returns
    None.

  @Param
    None.

  @Example
    <code>
    // Set RA10 high (1)
    IO_RA10_SetHigh();
    </code>

*/
#define IO_RA10_SetHigh()          (_LATA10 = 1)
/**
  @Summary
    Sets the GPIO pin, RA10, low using LATA10.

  @Description
    Sets the GPIO pin, RA10, low using LATA10.

  @Preconditions
    The RA10 must be set to an output.

  @Returns
    None.

  @Param
    None.

  @Example
    <code>
    // Set RA10 low (0)
    IO_RA10_SetLow();
    </code>

*/
#define IO_RA10_SetLow()           (_LATA10 = 0)
/**
  @Summary
    Toggles the GPIO pin, RA10, using LATA10.

  @Description
    Toggles the GPIO pin, RA10, using LATA10.

  @Preconditions
    The RA10 must be set to an output.

  @Returns
    None.

  @Param
    None.

  @Example
    <code>
    // Toggle RA10
    IO_RA10_Toggle();
    </code>

*/
#define IO_RA10_Toggle()           (_LATA10 ^= 1)
/**
  @Summary
    Reads the value of the GPIO pin, RA10.

  @Description
    Reads the value of the GPIO pin, RA10.

  @Preconditions
    None.

  @Returns
    None.

  @Param
    None.

  @Example
    <code>
    uint16_t portValue;

    // Read RA10
    postValue = IO_RA10_GetValue();
    </code>

*/
#define IO_RA10_GetValue()         _RA10
/**
  @Summary
    Configures the GPIO pin, RA10, as an input.

  @Description
    Configures the GPIO pin, RA10, as an input.

  @Preconditions
    None.

  @Returns
    None.

  @Param
    None.

  @Example
    <code>
    // Sets the RA10 as an input
    IO_RA10_SetDigitalInput();
    </code>

*/
#define IO_RA10_SetDigitalInput()  (_TRISA10 = 1)
/**
  @Summary
    Configures the GPIO pin, RA10, as an output.

  @Description
    Configures the GPIO pin, RA10, as an output.

  @Preconditions
    None.

  @Returns
    None.

  @Param
    None.

  @Example
    <code>
    // Sets the RA10 as an output
    IO_RA10_SetDigitalOutput();
    </code>

*/
#define IO_RA10_SetDigitalOutput() (_TRISA10 = 0)
/**
  @Summary
    Sets the GPIO pin, RA2, high using LATA2.

  @Description
    Sets the GPIO pin, RA2, high using LATA2.

  @Preconditions
    The RA2 must be set to an output.

  @Returns
    None.

  @Param
    None.

  @Example
    <code>
    // Set RA2 high (1)
    BTN4_SetHigh();
    </code>

*/
#define BTN4_SetHigh()          (_LATA2 = 1)
/**
  @Summary
    Sets the GPIO pin, RA2, low using LATA2.

  @Description
    Sets the GPIO pin, RA2, low using LATA2.

  @Preconditions
    The RA2 must be set to an output.

  @Returns
    None.

  @Param
    None.

  @Example
    <code>
    // Set RA2 low (0)
    BTN4_SetLow();
    </code>

*/
#define BTN4_SetLow()           (_LATA2 = 0)
/**
  @Summary
    Toggles the GPIO pin, RA2, using LATA2.

  @Description
    Toggles the GPIO pin, RA2, using LATA2.

  @Preconditions
    The RA2 must be set to an output.

  @Returns
    None.

  @Param
    None.

  @Example
    <code>
    // Toggle RA2
    BTN4_Toggle();
    </code>

*/
#define BTN4_Toggle()           (_LATA2 ^= 1)
/**
  @Summary
    Reads the value of the GPIO pin, RA2.

  @Description
    Reads the value of the GPIO pin, RA2.

  @Preconditions
    None.

  @Returns
    None.

  @Param
    None.

  @Example
    <code>
    uint16_t portValue;

    // Read RA2
    postValue = BTN4_GetValue();
    </code>

*/
#define BTN4_GetValue()         _RA2
/**
  @Summary
    Configures the GPIO pin, RA2, as an input.

  @Description
    Configures the GPIO pin, RA2, as an input.

  @Preconditions
    None.

  @Returns
    None.

  @Param
    None.

  @Example
    <code>
    // Sets the RA2 as an input
    BTN4_SetDigitalInput();
    </code>

*/
#define BTN4_SetDigitalInput()  (_TRISA2 = 1)
/**
  @Summary
    Configures the GPIO pin, RA2, as an output.

  @Description
    Configures the GPIO pin, RA2, as an output.

  @Preconditions
    None.

  @Returns
    None.

  @Param
    None.

  @Example
    <code>
    // Sets the RA2 as an output
    BTN4_SetDigitalOutput();
    </code>

*/
#define BTN4_SetDigitalOutput() (_TRISA2 = 0)
/**
  @Summary
    Sets the GPIO pin, RA3, high using LATA3.

  @Description
    Sets the GPIO pin, RA3, high using LATA3.

  @Preconditions
    The RA3 must be set to an output.

  @Returns
    None.

  @Param
    None.

  @Example
    <code>
    // Set RA3 high (1)
    IO_RA3_SetHigh();
    </code>

*/
#define IO_RA3_SetHigh()          (_LATA3 = 1)
/**
  @Summary
    Sets the GPIO pin, RA3, low using LATA3.

  @Description
    Sets the GPIO pin, RA3, low using LATA3.

  @Preconditions
    The RA3 must be set to an output.

  @Returns
    None.

  @Param
    None.

  @Example
    <code>
    // Set RA3 low (0)
    IO_RA3_SetLow();
    </code>

*/
#define IO_RA3_SetLow()           (_LATA3 = 0)
/**
  @Summary
    Toggles the GPIO pin, RA3, using LATA3.

  @Description
    Toggles the GPIO pin, RA3, using LATA3.

  @Preconditions
    The RA3 must be set to an output.

  @Returns
    None.

  @Param
    None.

  @Example
    <code>
    // Toggle RA3
    IO_RA3_Toggle();
    </code>
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

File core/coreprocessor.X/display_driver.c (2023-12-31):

/*
 * File:   display_driver.c
 * Author: greengravity
 *
 * Created on 14. Januar 2023, 16:01
 */

#include "mcc_generated_files/system.h"
#include "mcc_generated_files/spi1_driver.h"
#include "mcc_generated_files/pin_manager.h"
#include "mcc_generated_files/oc1.h"
#include "mcc_ext.h"
#include "main.h"
#include "display_driver.h"
#include <stdio.h>
#include <string.h>

static uint8_t _height, _width, _rotation;
static uint8_t _charx=0, _chary=0;
static uint8_t _startwrite, _endwrite;


const uint8_t
  Bcmd[] = {                        // Init commands for 7735B screens
    18,                             // 18 commands in list:
    ST77XX_SWRESET,   ST_CMD_DELAY, //  1: Software reset, no args, w/delay
      50,                           //     50 ms delay
    ST77XX_SLPOUT,    ST_CMD_DELAY, //  2: Out of sleep mode, no args, w/delay
      255,                          //     255 = max (500 ms) delay
    ST77XX_COLMOD,  1+ST_CMD_DELAY, //  3: Set color mode, 1 arg + delay:
      0x05,                         //     16-bit color
      10,                           //     10 ms delay
    ST7735_FRMCTR1, 3+ST_CMD_DELAY, //  4: Frame rate control, 3 args + delay:
      0x00,                         //     fastest refresh
      0x06,                         //     6 lines front porch
      0x03,                         //     3 lines back porch
      10,                           //     10 ms delay
    ST77XX_MADCTL,  1,              //  5: Mem access ctl (directions), 1 arg:
      0x08,                         //     Row/col addr, bottom-top refresh
    ST7735_DISSET5, 2,              //  6: Display settings #5, 2 args:
      0x15,                         //     1 clk cycle nonoverlap, 2 cycle gate
                                    //     rise, 3 cycle osc equalize
      0x02,                         //     Fix on VTL
    ST7735_INVCTR,  1,              //  7: Display inversion control, 1 arg:
      0x0,                          //     Line inversion
    ST7735_PWCTR1,  2+ST_CMD_DELAY, //  8: Power control, 2 args + delay:
      0x02,                         //     GVDD = 4.7V
      0x70,                         //     1.0uA
      10,                           //     10 ms delay
    ST7735_PWCTR2,  1,              //  9: Power control, 1 arg, no delay:
      0x05,                         //     VGH = 14.7V, VGL = -7.35V
    ST7735_PWCTR3,  2,              // 10: Power control, 2 args, no delay:
      0x01,                         //     Opamp current small
      0x02,                         //     Boost frequency
    ST7735_VMCTR1,  2+ST_CMD_DELAY, // 11: Power control, 2 args + delay:
      0x3C,                         //     VCOMH = 4V
      0x38,                         //     VCOML = -1.1V
      10,                           //     10 ms delay
    ST7735_PWCTR6,  2,              // 12: Power control, 2 args, no delay:
      0x11, 0x15,
    ST7735_GMCTRP1,16,              // 13: Gamma Adjustments (pos. polarity), 16 args + delay:
      0x09, 0x16, 0x09, 0x20,       //     (Not entirely necessary, but provides
      0x21, 0x1B, 0x13, 0x19,       //      accurate colors)
      0x17, 0x15, 0x1E, 0x2B,
      0x04, 0x05, 0x02, 0x0E,
    ST7735_GMCTRN1,16+ST_CMD_DELAY, // 14: Gamma Adjustments (neg. polarity), 16 args + delay:
      0x0B, 0x14, 0x08, 0x1E,       //     (Not entirely necessary, but provides
      0x22, 0x1D, 0x18, 0x1E,       //      accurate colors)
      0x1B, 0x1A, 0x24, 0x2B,
      0x06, 0x06, 0x02, 0x0F,
      10,                           //     10 ms delay
    ST77XX_CASET,   4,              // 15: Column addr set, 4 args, no delay:
      0x00, 0x02,                   //     XSTART = 2
      0x00, 0x81,                   //     XEND = 129
    ST77XX_RASET,   4,              // 16: Row addr set, 4 args, no delay:
      0x00, 0x02,                   //     XSTART = 1
      0x00, 0x81,                   //     XEND = 160
    ST77XX_NORON,     ST_CMD_DELAY, // 17: Normal display on, no args, w/delay
      10,                           //     10 ms delay
    ST77XX_DISPON,    ST_CMD_DELAY, // 18: Main screen turn on, no args, delay
      255 },                        //     255 = max (500 ms) delay

        
  Rcmd1[] = {                       // 7735R init, part 1 (red or green tab)
    15,                             // 15 commands in list:
    ST77XX_SWRESET,   ST_CMD_DELAY, //  1: Software reset, 0 args, w/delay
      150,                          //     150 ms delay
    ST77XX_SLPOUT,    ST_CMD_DELAY, //  2: Out of sleep mode, 0 args, w/delay
      255,                          //     500 ms delay
    ST7735_FRMCTR1, 3,              //  3: Framerate ctrl - normal mode, 3 arg:
      0x01, 0x2C, 0x2D,             //     Rate = fosc/(1x2+40) * (LINE+2C+2D)
    ST7735_FRMCTR2, 3,              //  4: Framerate ctrl - idle mode, 3 args:
      0x01, 0x2C, 0x2D,             //     Rate = fosc/(1x2+40) * (LINE+2C+2D)
    ST7735_FRMCTR3, 6,              //  5: Framerate - partial mode, 6 args:
      0x01, 0x2C, 0x2D,             //     Dot inversion mode
      0x01, 0x2C, 0x2D,             //     Line inversion mode
    ST7735_INVCTR,  1,              //  6: Display inversion ctrl, 1 arg:
      0x07,                         //     No inversion
    ST7735_PWCTR1,  3,              //  7: Power control, 3 args, no delay:
      0xA2,
      0x02,                         //     -4.6V
      0x84,                         //     AUTO mode
    ST7735_PWCTR2,  1,              //  8: Power control, 1 arg, no delay:
      0xC5,                         //     VGH25=2.4C VGSEL=-10 VGH=3 * AVDD
    ST7735_PWCTR3,  2,              //  9: Power control, 2 args, no delay:
      0x0A,                         //     Opamp current small
      0x00,                         //     Boost frequency
    ST7735_PWCTR4,  2,              // 10: Power control, 2 args, no delay:
      0x8A,                         //     BCLK/2,
      0x2A,                         //     opamp current small & medium low
    ST7735_PWCTR5,  2,              // 11: Power control, 2 args, no delay:
      0x8A, 0xEE,
    ST7735_VMCTR1,  1,              // 12: Power control, 1 arg, no delay:
      0x0E,
    ST77XX_INVOFF,  0,              // 13: Don't invert display, no args
    ST77XX_MADCTL,  1,              // 14: Mem access ctl (directions), 1 arg:
      0xC8,                         //     row/col addr, bottom-top refresh
    ST77XX_COLMOD,  1,              // 15: set color mode, 1 arg, no delay:
      0x05 },                       //     16-bit color
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

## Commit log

2022-12-21 Schematic symbol
    [datakeyboard.kicad_pcb, datakeyboard.kicad_sch]
2022-12-28 More schematic
    [datakeyboard.kicad_sch]
2022-12-29 Charging and battery protection
2023-01-02 Power supply
    [datakeyboard.kicad_sch]
2023-01-03 Display light
    [datakeyboard.kicad_sch]
2023-01-05 Wire up SDCard and buttons
    [datakeyboard.kicad_sch]
2023-01-14 Continue schematics
    [datakeyboard.kicad_sch]
2023-01-21 Adjust schematics to code
    [datakeyboard.kicad_sch]
2023-01-21 Pin reconfiguration
2023-01-21 Fine tune schematic (grounding pins)
    [datakeyboard.kicad_sch]
2023-01-25 Add case switch
    [datakeyboard.kicad_sch]
2023-01-26 Pin input
2023-01-27 Board layout
    [datakeyboard.kicad_pcb, datakeyboard.kicad_sch]
2023-01-29 Start board layout
    [datakeyboard.kicad_pcb, datakeyboard.kicad_sch]
2023-01-29 Finish PCB layout
    [datakeyboard.kicad_pcb, datakeyboard.kicad_sch]
2023-01-30 Gerber files
    [datakeyboard.kicad_pcb]
2023-02-16 Add second regulator to bypass charger
    [datakeyboard.kicad_pcb, datakeyboard.kicad_sch]
2023-02-16 Update PDF
    [datakeyboard.kicad_pcb]
2023-02-18 Control charging by microcontroller
    [datakeyboard.kicad_pcb, datakeyboard.kicad_sch]
2023-02-19 Resize solder pads
    [datakeyboard.kicad_pcb, datakeyboard.kicad_sch]
2023-02-21 Last features
    [Config_1.txt, Config_2.txt, Config_3.txt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]
2023-02-26 Redesign power supply to bypass charger when running from USB
    [datakeyboard.kicad_pcb, datakeyboard.kicad_sch]
2023-02-26 Add thermal reliefs on ground plane
    [datakeyboard.kicad_pcb]
2023-03-18 Fix display orientation Switch VBAT, GND text on silk screen Movie VIAs out of the way of the button solder pads.
    [datakeyboard.kicad_pcb, datakeyboard.kicad_sch]
2023-03-19 Different Buttondefinitions
2023-11-05 Button configuration changed
2023-11-11 Added 3D Model for housing
    [datakeyboard.csv, datakeyboard.kicad_sch, housing_complete.blend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]
2023-11-17 Reduce current to increase battery life
    [datakeyboard-B_Cu.gbr, datakeyboard-B_Mask.gbr, datakeyboard-B_Paste.gbr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]
2023-11-19 Refine Charge control
    [buttons.stl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]
2023-11-24 Fix the Masterkey verification after entering the Pin
    [logic.h]
2023-11-25 clean up stuff
    [buttons.stl, components.csv, housing_complete.blend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]
2023-12-22 Localization simplified
    [buttons.stl, datakeyboard.csv, deckel.stl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]
